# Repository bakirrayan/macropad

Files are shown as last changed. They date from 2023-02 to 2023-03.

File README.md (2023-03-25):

# macropad

## Composition
- 16 key switchs
- 1 oled screen 0.96
- 2 rotary encoders

## PCB
PCB files can be found in "macro" folder along with the zip file to order it from pcbway

## Code
### Installation process
- Copy /pico_files/adafruit-circuitpython-raspberry_pi_pico-fr-8.0.4 to your Rpi pico 
- After a few seconds your pico will restart and a disk named circuitpython will show up
- Copy /pico_files/kmk /pico_files/lib /pico_files/code.py /pico_files/boot.py /pico_files/oled.py to the circuitpython disk
- The keyboard should work instatly

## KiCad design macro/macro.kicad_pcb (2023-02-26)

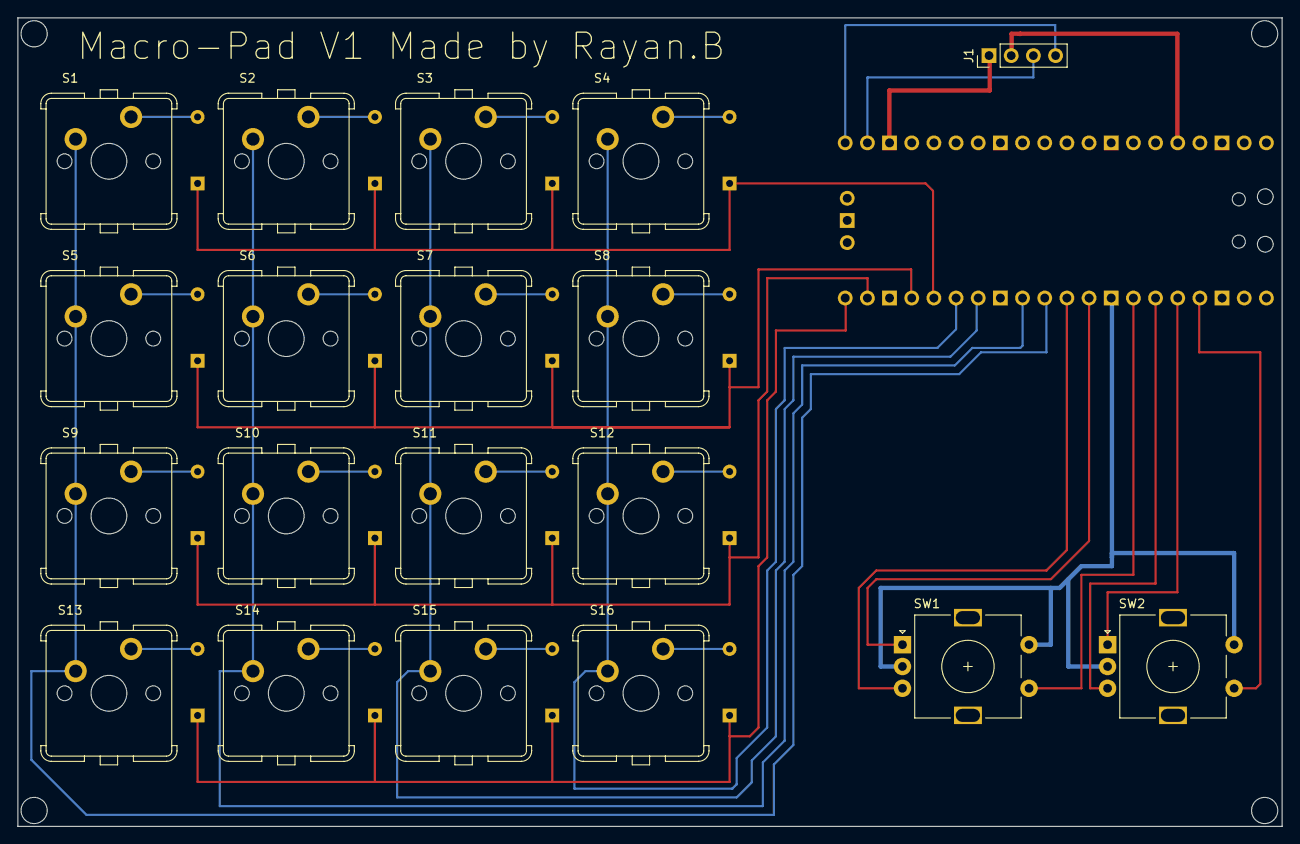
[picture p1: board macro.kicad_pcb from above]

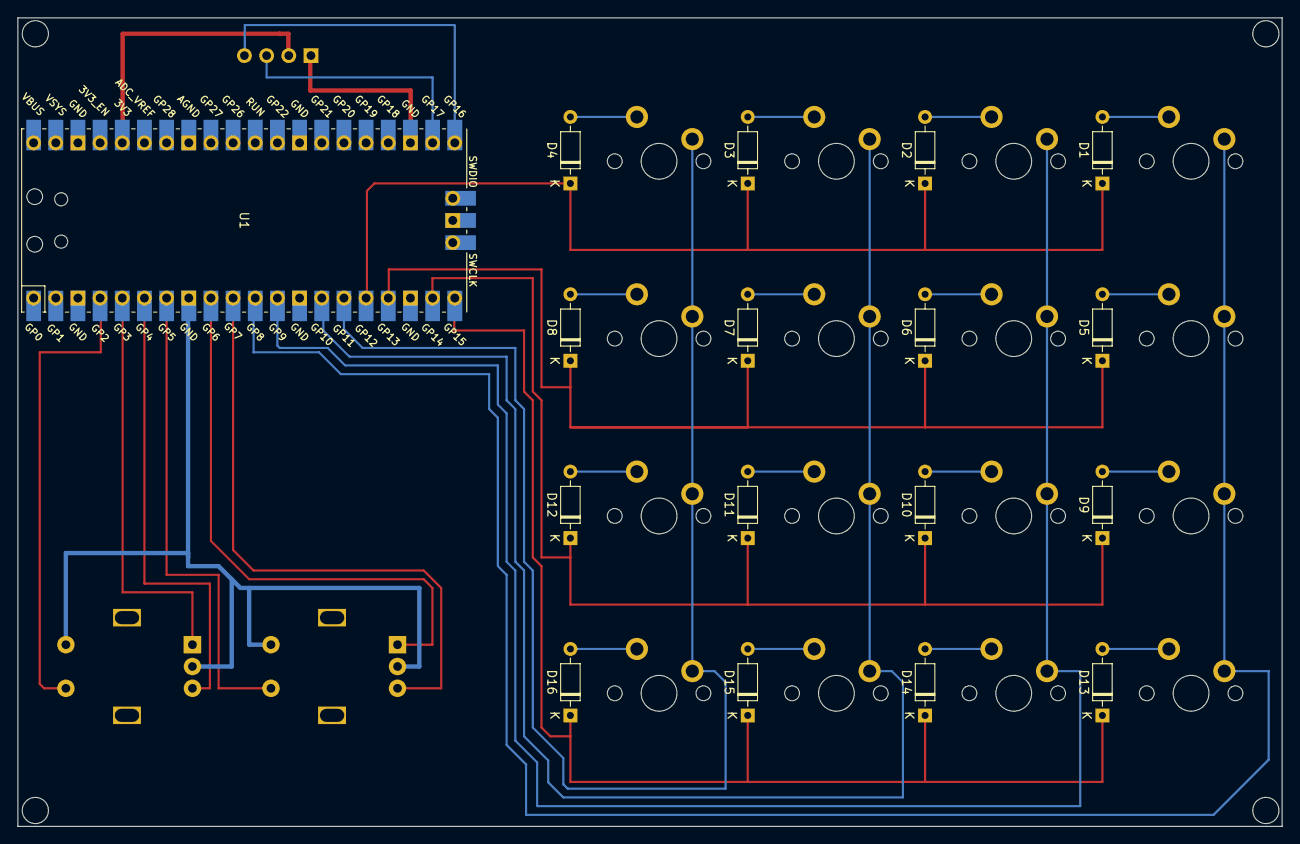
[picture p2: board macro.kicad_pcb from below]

Board: 2 copper layers, 144.9 x 92.6 mm, 36 parts (17 on the bottom side), 35 nets.

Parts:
D1, D2, D3, D4, D5, D6, D7, D8, D9, D10, D11, D12, D13, D14, D15, D16: 1N4148; D_DO-35_SOD27_P7.62mm_Horizontal
J1: Conn_01x04_Socket; PinHeader_1x04_P2.54mm_Vertical
S1, S2, S3, S4, S5, S6, S7, S8, S9, S10, S11, S12, S13, S14, S15, S16: CHERRY_CHERRY_MX
SW1, SW2: RotaryEncoder_Switch; RotaryEncoder_Alps_EC11E-Switch_Vertical_H20mm
U1: Pico; RPi_Pico_SMD_TH

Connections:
/c1: SW1.S1, U1.7 (GPIO5)
/c21: SW2.S1, U1.4 (GPIO2)
/col1: S1.S1, S5.S1, S9.S1, S13.S1, U1.11 (GPIO8)
/col2: S2.S1, S6.S1, S10.S1, S14.S1, U1.12 (GPIO9)
/col3: S3.S1, S7.S1, S11.S1, S15.S1, U1.14 (GPIO10)
/col4: S4.S1, S8.S1, S12.S1, S16.S1, U1.15 (GPIO11)
/gn: SW1.C, SW1.S2, SW2.C, SW2.S2, U1.8 (GND)
/gn2: J1.1, U1.23 (GND)
/r1a: SW1.A, U1.9 (GPIO6)
/r1b: SW1.B, U1.10 (GPIO7)
/r2a: SW2.A, U1.5 (GPIO3)
/r2b: SW2.B, U1.6 (GPIO4)
/raw1: D1.1 (K), D2.1 (K), D3.1 (K), D4.1 (K), U1.16 (GPIO12)
/raw2: D5.1 (K), D6.1 (K), D7.1 (K), D8.1 (K), U1.17 (GPIO13)
/raw3: D9.1 (K), D10.1 (K), D11.1 (K), D12.1 (K), U1.19 (GPIO14)
/raw4: D13.1 (K), D14.1 (K), D15.1 (K), D16.1 (K), U1.20 (GPIO15)
/scl: J1.3, U1.22 (GPIO17)
/sda: J1.4, U1.21 (GPIO16)
/vcc: J1.2, U1.36 (3V3)
unnamed: D1.2 (A), S1.S2
unnamed: D2.2 (A), S2.S2
unnamed: D3.2 (A), S3.S2
unnamed: D4.2 (A), S4.S2
unnamed: D5.2 (A), S5.S2
unnamed: D6.2 (A), S6.S2
unnamed: D7.2 (A), S7.S2
unnamed: D8.2 (A), S8.S2
unnamed: D9.2 (A), S9.S2
unnamed: D10.2 (A), S10.S2
unnamed: D11.2 (A), S11.S2
unnamed: D12.2 (A), S12.S2
unnamed: D13.2 (A), S13.S2
unnamed: D14.2 (A), S14.S2
unnamed: D15.2 (A), S15.S2
unnamed: D16.2 (A), S16.S2

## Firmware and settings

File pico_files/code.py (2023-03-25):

import board
from kmk.kmk_keyboard import KMKKeyboard
from kmk.keys import KC
from kmk.scanners import DiodeOrientation
from kmk.modules.encoder import EncoderHandler
from kmk.modules.layers import Layers
from kmk.handlers.sequences import simple_key_sequence
from kmk.extensions.media_keys import MediaKeys
from oled import Oled,OledDisplayMode,OledReactionType,OledData

print("Starting")

keyboard = KMKKeyboard()

encoder_handler = EncoderHandler()
media_keys = MediaKeys()
layers_ext = Layers()

keyboard.modules = [encoder_handler, media_keys, layers_ext]

oled_display_data=OledData(text={0:OledReactionType.LAYER,1:["Layer ==> 0","Layer ==> 1"]})
oled_ext = Oled(oled_display_data,toDisplay=OledDisplayMode.TXT,flip=False)

keyboard.extensions.append(oled_ext)

keyboard.col_pins = (board.GP8, board.GP9, board.GP10, board.GP11)
keyboard.row_pins = (board.GP12, board.GP13, board.GP14, board.GP15)
keyboard.diode_orientation = DiodeOrientation.COL2ROW

encoder_handler.pins = ((board.GP6, board.GP7, board.GP5, False),
                        (board.GP3, board.GP4, board.GP2, False),)
# transparent key
_______ = KC.TRNS
# csgo keys
pistole = KC.N2
gun = KC.N1
knife = KC.N3
# VS Code keys
NEXT = simple_key_sequence( ( KC.LCTL(no_release=True), KC.LALT(no_release=True), KC.UP, ) )


keyboard.keymap = [
    # csgo
    [   _______,   _______,   _______,   _______,
        NEXT,   gun,   pistole,   knife,
        KC.LSFT,   KC.q,   KC.w,   KC.r,
        KC.LCTL,   KC.a,   KC.s,   KC.d
    ],
    # VS Code
    [   KC.TAB,     KC.F1,     KC.F2,     KC.F3,
        KC.y,     KC.F4,     KC.F5,     KC.F6,
        KC.w,     KC.F7,   KC.F8,     KC.F9,
        _______,    _______,    _______,    _______
    ]
]

encoder_handler.map = [ # Layer 1
                        ((KC.VOLD, KC.VOLU, KC.MUTE), (KC.BRID, KC.BRIU, KC.TO(1)),),
                        # Layer 2
                        ((KC.VOLD, KC.VOLU, KC.MUTE), (_______, _______, KC.TO(0)),)]

if __name__ == '__main__':
    keyboard.go()

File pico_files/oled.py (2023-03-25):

import busio, terminalio, displayio, gc, board
import adafruit_displayio_ssd1306
from adafruit_display_text import label
from kmk.extensions import Extension


class OledDisplayMode:
    TXT = 0
    IMG = 1


class OledReactionType:
    STATIC = 0
    LAYER = 1


class OledData:
    def __init__(
        self,
        image=None,
        text=None,
    ):
        if image:
            self.data = [image]
        elif text:
            self.data = [text]


class Oled(Extension):
    def __init__(
        self,
        views,
        toDisplay=OledDisplayMode.TXT,
        oWidth=128,
        oHeight=64,
        flip: bool = False,
    ):
        displayio.release_displays()
        self.rotation = 180 if flip else 0
        self._views = views.data
        self._toDisplay = toDisplay
        self._width = oWidth
        self._height = oHeight
        self._prevLayers = 0
        gc.collect()

    def returnCurrectRenderText(self, layer, singleView):
        # for now we only have static things and react to layers.
        # But when we react to battery % and wpm we can handle the logic here
        if singleView[0] == OledReactionType.STATIC:
            return singleView[1][0]
        if singleView[0] == OledReactionType.LAYER:
            return singleView[1][layer]

    def renderOledTextLayer(self, layer):
        splash = displayio.Group()
        splash.append(
            label.Label(
                terminalio.FONT,
                text=self.returnCurrectRenderText(layer, self._views[0]),
                color=0xFFFFFF,
                x=0,
                y=10,
            )
        )
        self._display.show(splash)
        gc.collect()

    def renderOledImgLayer(self, layer):
        splash = displayio.Group()
        odb = displayio.OnDiskBitmap(
            '/' + self.returnCurrectRenderText(layer, self._views[0])
        )
        image = displayio.TileGrid(odb, pixel_shader=odb.pixel_shader)
        splash.append(image)
        self._display.show(splash)
        gc.collect()

    def updateOLED(self, sandbox):
        if self._toDisplay == OledDisplayMode.TXT:
            self.renderOledTextLayer(sandbox.active_layers[0])
        if self._toDisplay == OledDisplayMode.IMG:
            self.renderOledImgLayer(sandbox.active_layers[0])
        gc.collect()

    def on_runtime_enable(self, sandbox):
        return

    def on_runtime_disable(self, sandbox):
        return

    def during_bootup(self, keyboard):
        displayio.release_displays()
        sda, scl = board.GP16, board.GP17
        i2c = busio.I2C(scl, sda)
        self._display = adafruit_displayio_ssd1306.SSD1306(
            displayio.I2CDisplay(i2c, device_address=0x3C),
            width=self._width,
            height=self._height,
            rotation=self.rotation,
        )
        if self._toDisplay == OledDisplayMode.TXT:
            self.renderOledTextLayer(0)
        if self._toDisplay == OledDisplayMode.IMG:
            self.renderOledImgLayer(0)
        return

    def before_matrix_scan(self, sandbox):
        if sandbox.active_layers[0] != self._prevLayers:
            self._prevLayers = sandbox.active_layers[0]
            self.updateOLED(sandbox)
        return

    def after_matrix_scan(self, sandbox):

        return

    def before_hid_send(self, sandbox):
        return

    def after_hid_send(self, sandbox):
        return

    def on_powersave_enable(self, sandbox):
        return

    def on_powersave_disable(self, sandbox):
        return

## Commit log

2023-02-26 some changes on the pcb
    [macro.kicad_pcb, macro.kicad_sch]
2023-02-26 some changes on the gerbers files
